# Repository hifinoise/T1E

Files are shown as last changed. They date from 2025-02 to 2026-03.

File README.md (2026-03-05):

# T1E - E-Paper Watch

> Time. For time's sake.

**The T1E is an open-source ePaper smartwatch that lasts for days, not hours. Minimal. Hackable. Yours.**

Because checking your phone for the time is so last decade. The T1E prioritises battery life over flashy animations. Built around an ESP32 microcontroller and a DS3231 RTC, it's designed for people who want their timepiece to actually keep time without requiring daily charging rituals.

---

## Features

- **ePaper Display:** Crystal clear in direct sunlight and uses minimal power.
- **4+ Days Battery Life:** Target 16+ days using intelligent partial refreshes. Charge less, live more.
- **Real-Time Clock:** DS3231 maintains accurate timekeeping even when the main MCU sleeps.
- **Deep Sleep Mode:** Intelligent power management. [Not Implemented on IDF Yet!]
- **Fully Hackable:** 100% open-source hardware, firmware, and mechanical designs.
- **Custom App Modes:** Various watch faces, a Pomodoro timer, a dice roller, and Conway's Game of Life built in.

## What's This Then?

This repository contains the full hardware designs, 3D-printable case models, and the **official, native ESP-IDF firmware** (built via PlatformIO) for the T1E E-Paper Watch. 

Every design choice has a clear reason: the ESP32 wakes up just long enough to refresh the screen, while the external RTC handles timekeeping at micro-amp power levels.

## Repository Contents

```
├── hardware/
│   ├── schematics/        # EasyEDA schematic files (and exported PDFs)
│   ├── pcb/               # PCB layout and gerbers
│   └── bom.csv            # Bill of materials
├── mechanical/
│   ├── case/              # 3D printable case files (STL/STEP)
│   └── assembly/          # Assembly instructions
├── firmware/              
│   ├── V2a/                # ESP-IDF Version (Experimental)
│   └── V1.1/               # Old Arduino-based code
└── docs/                  # Build guides and documentation
```

## Technical Specifications

- **MCU:** ESP32-C3 / ESP32-C6 (RISC-V, Dual-core, WiFi/BLE)
- **Display:** High-contrast ePaper display
- **RTC:** DS3231 with integrated crystal 
- **Power:** LiPo battery with BMS
- **Connectivity:** WiFi 2.4GHz & Bluetooth LE

## Getting Started

### Prerequisites

- PlatformIO
- 3D printer (for the case)
- Basic soldering skills
- Patience (surprisingly important for embedded development)

### Hardware Assembly

1. **PCB Assembly:** Solder components according to the BOM and assembly guide.
2. **Case Printing:** Print case parts using provided STL files.
3. **Final Assembly:** Mount PCB in case, connect battery, install display.

*(Detailed assembly instructions are in `/docs/assembly.md`)*

### Firmware Setup

1. Install [PlatformIO](https://platformio.org/).
2. Clone this repository.
3. Open the repository in PlatformIO.
4. Select your build environment (`env:t1e-c3` or `env:t1e-c6`).
5. Build and flash the firmware to the ESP32 via USB.
6. Set the initial time via the serial console or by configuring the WiFi sync credentials.

## Design Philosophy & Contributing

- **Battery Life First:** ePaper and an RTC combo for minimal power consumption.
- **Hackable by Design:** Built to be modified—not just used. Feel free to tweak the display update logic, design a new case, or implement a fresh display driver.
- **Contributing:** Pull requests are always welcome! Help is particularly appreciated with extreme power optimisation, new UI app modes, and alternative display drivers.

---

## License

- **Hardware:** CERN-OHL-W v2
- **Firmware:** MIT License
- **Mechanical:** CC BY-SA 4.0

## Support & About
For questions, bug reports, or general discussion, open an issue on GitHub.

> *"There is never time in the future in which we will work out our salvation. The challenge is in the moment; the time is always now."* — James Baldwin

*The T1E is a project by [Ampere Works](https://ampere.works/t1e) - part of a mission to make hardware design approachable without dumbing it down.*

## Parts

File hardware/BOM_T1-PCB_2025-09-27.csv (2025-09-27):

ID | Name | Designator | Footprint | Quantity | Manufacturer Part | Manufacturer | Supplier | Supplier Part | Price
1 | Waveshare 1.54inch e-Paper | U1 | WAVESHARE 1.54INCH EPAPER | 1
2 | XIAO ESP32C3 | U8 | XIAO-ESP32C3-MODULE14P-2.54-21X17.8MM | 1
3 | 220kΩ | R3,R4 | RES-TH_BD1.8-L3.2-P7.20-D0.4 | 2 | MF1/8W-220KΩ±1%T52 | 华星机电 | LCSC | C713940 | 0.006
4 | LiPo 502030 3.7V | U6 | BATTERY LIPO 502030 3.7V | 1
5 | Switch | S1,S2 | 6X6X6.0MM 2L THT TACTILE SWITCH | 2
6 | CR927b_Pin | U2 | CR927_PINS | 1
7 | 100kΩ | R1,R2 | RES-TH_BD1.8-L3.2-P7.20-D0.4 | 2 | MF1/8W-100KΩ±1%T52 | 华星机电 | LCSC | C713934 | 0.007
8 | BUZZER-4.0X4.0-2P-SMD | U3 | BUZZER-4.0X4.0-2P-SMD | 1 | GSC4417YA-16R4000 | INGHAi | LCSC | C255308 | 0.994
9 | DS3231 PI | U7 | DS3231 PI | 1
10 | Wareshare eInk SPI Interface | U5 | WAVESHARE_1.54_EINK_DISPLAY_FOOTPRINT | 1

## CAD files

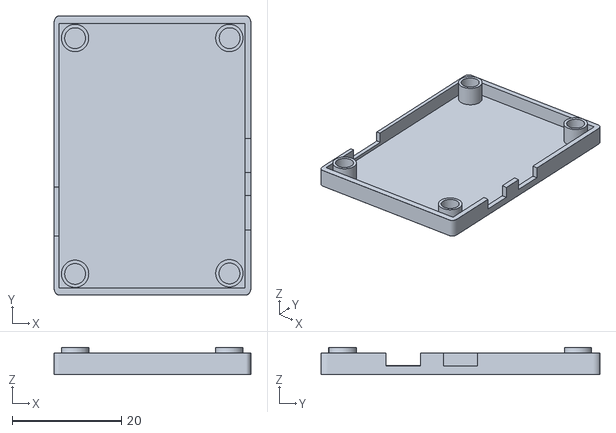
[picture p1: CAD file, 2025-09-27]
mechanical/Case-Bottom-M2.stl
36.0 x 51.0 x 5.00

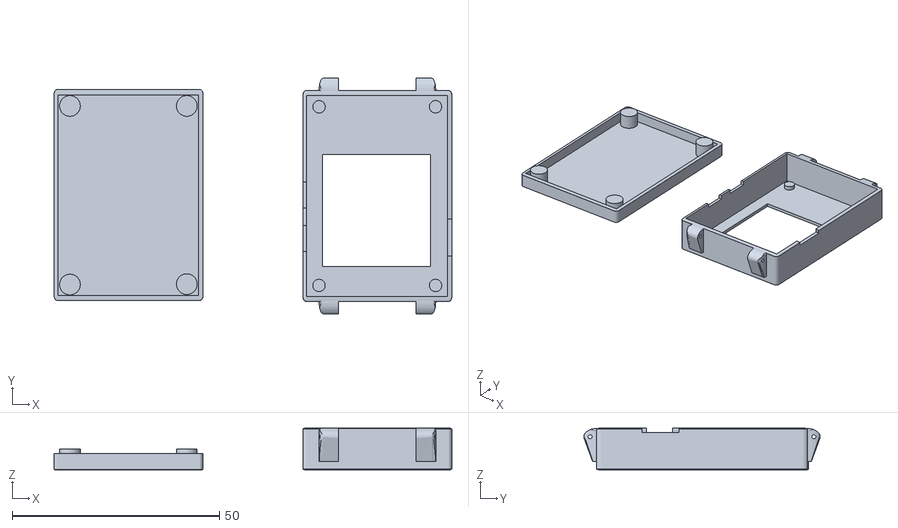
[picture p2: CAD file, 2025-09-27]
mechanical/Case-M2.stl
96.1 x 57.0 x 10.1

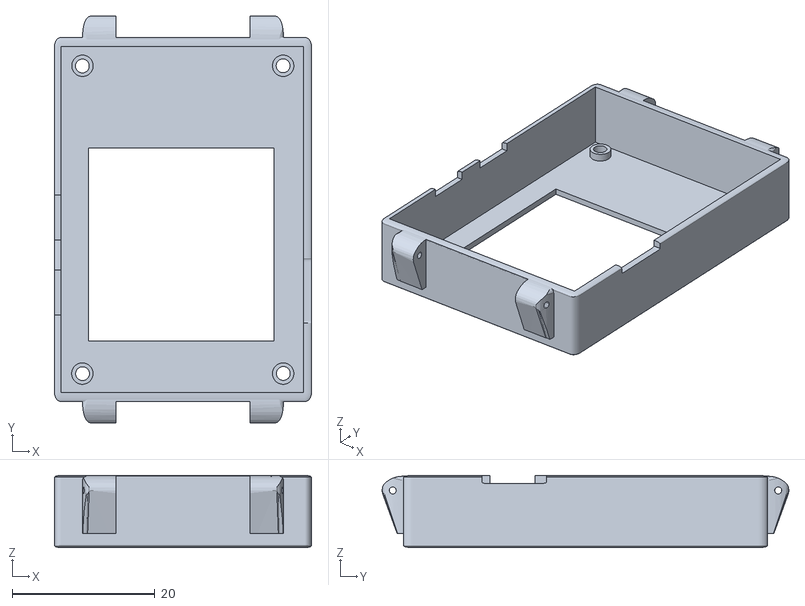
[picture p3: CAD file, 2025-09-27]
mechanical/Case-Top-M2.stl
36.0 x 57.0 x 10.1

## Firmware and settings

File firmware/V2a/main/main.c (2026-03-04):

#include <stdio.h>
#include <string.h>
#include "esp_log.h"
#include "esp_sleep.h"
#include "esp_attr.h"
#include "freertos/FreeRTOS.h"
#include "freertos/task.h"

#include "hal/hal.h"
#include "hal/hal_pins.h"
#include "drivers/epd/epd.h"
#include "drivers/epd/epd_gfx.h"
#include "drivers/rtc/rtc_ds3231.h"
#include "app/state.h"
#include "app/modes/mode_clock.h"
#include "app/modes/mode_life_clock.h"
#include "app/modes/mode_dice.h"
#include "app/modes/mode_art.h"
#include "app/modes/mode_pomo.h"
#include "app/modes/mode_life.h"
#include "app/modes/mode_settings.h"

static const char *TAG = "t1e";

// Framebuffers in regular SRAM — NOT RTC slow memory
static uint8_t fb[EPD_FB_SIZE];
static uint8_t prev_fb[EPD_FB_SIZE];

// refresh_speed index → update interval in milliseconds
static const uint32_t REFRESH_MS[REFRESH_SPEED_COUNT] = {100, 250, 500, 1000, 10000, 60000};

// deghost_idx → ms between full-white deghost refresh (0 = disabled)
static const uint32_t DEGHOST_MS[DEGHOST_IDX_COUNT] = {5*60*1000, 15*60*1000, 30*60*1000, 0};

static void render(t1e_state_t *s) {
    switch (s->mode) {
        case MODE_CLOCK:      mode_clock_render(fb, s);      break;
        case MODE_LIFE_CLOCK: mode_life_clock_render(fb, s); break;
        case MODE_DICE:       mode_dice_render(fb, s);       break;
        case MODE_ART:        mode_art_render(fb, s);        break;
        case MODE_POMO:       mode_pomo_render(fb, s);       break;
        case MODE_LIFE:       mode_life_render(fb, s);       break;
        case MODE_SETTINGS:   mode_settings_render(fb, s);   break;
        default:              mode_clock_render(fb, s);       break;
    }
}

static void action(t1e_state_t *s) {
    switch (s->mode) {
        case MODE_CLOCK:      mode_clock_action(s);      break;
        case MODE_LIFE_CLOCK: mode_life_clock_action(s); break;
        case MODE_DICE:       mode_dice_action(s);       break;
        case MODE_ART:        mode_art_action(s);        break;
        case MODE_POMO:       mode_pomo_action(s);       break;
        case MODE_LIFE:       mode_life_action(s);       break;
        case MODE_SETTINGS:   mode_settings_action(s);   break;
        default: break;
    }
}

void app_main(void) {
    ESP_LOGI(TAG, "=== T1E BOOT ===");

    hal_buttons_init();
    hal_power_init();
    if (!rtc_init()) ESP_LOGE(TAG, "RTC FAILED");
    epd_init();

    t1e_state_t *s = state_get();
    if (s->magic != STATE_MAGIC) {
        state_init_defaults(s);
    }

    // Cold boot: full refresh to establish clean baseline in both RAMs
    render(s);
    if (s->display_invert)
        for (int i = 0; i < EPD_FB_SIZE; i++) fb[i] ^= 0xFF;
    epd_refresh_full(fb);
    memcpy(prev_fb, fb, EPD_FB_SIZE);

    uint32_t last_refresh = xTaskGetTickCount();
    uint32_t ghost_timer  = xTaskGetTickCount();

    while (1) {
        btn_state_t btn = hal_buttons_read();
        bool need_refresh = false;
        bool force_full   = false;
        bool do_deghost   = false;

        // --- Button A: secondary action ---
        if (btn.a) {
            action(s);
            need_refresh = true;
        }

        // --- Button B: confirm / mode advance ---
        if (btn.b) {
            if (s->mode == MODE_SETTINGS) {
                uint8_t invert_before = s->display_invert;
                mode_settings_confirm(s);
                // If invert just toggled, force a full refresh to reset RAM baseline
                if (s->display_invert != invert_before) force_full = true;
            } else if (s->mode == MODE_DICE) {
                if (s->dice_type < DICE_COUNT - 1) {
                    s->dice_type++;
                    s->last_roll = 0;
                } else {
                    s->dice_type = DICE_D20;
                    s->last_roll = 0;
                    state_next_mode(s);
                }
            } else {
                state_next_mode(s);
            }
            need_refresh = true;
        }

        // --- Time-based refresh ---
        uint32_t now = xTaskGetTickCount(); // ticks (1 tick = 1ms at default ESP32 config)
        uint32_t interval_ticks = pdMS_TO_TICKS(REFRESH_MS[s->refresh_speed % REFRESH_SPEED_COUNT]);
        // POMO countdown always needs 1s resolution
        if (s->mode == MODE_POMO && s->pomo_start) interval_ticks = pdMS_TO_TICKS(1000);

        static int last_min = -1;
        if (s->mode == MODE_CLOCK || s->mode == MODE_LIFE_CLOCK) {
            // For clock modes, only refresh when the minute actually changes.
            // We ignore interval_ticks entirely, but poll gently every 1 second.
            if (now - last_refresh >= pdMS_TO_TICKS(1000)) {
                rtc_time_t t = {0};
                if (rtc_get_time(&t)) {
                    if (t.min != last_min) {
                        need_refresh = true;
                        last_min = t.min;
                    }
                }
                last_refresh = now;
            }
        } else {
            // Normal global refresh interval for non-clock modes
            if (now - last_refresh >= interval_ticks) {
                need_refresh = true;
                last_refresh = now;
            }
        }

        // --- Deghost watchdog ---
        // Banks display to all-white then partial-refreshes back to current frame.
        // This clears image retention without a jarring double-flash.
        uint32_t dghost_ms = DEGHOST_MS[s->deghost_idx % DEGHOST_IDX_COUNT];
        if (dghost_ms > 0 && now - ghost_timer >= pdMS_TO_TICKS(dghost_ms)) {
            do_deghost   = true;
            need_refresh = true;
            ghost_timer  = now;
        }

        // --- Render and refresh ---
        if (need_refresh) {
            render(s);

            // Apply inversion if enabled
            if (s->display_invert)
                for (int i = 0; i < EPD_FB_SIZE; i++) fb[i] ^= 0xFF;

            if (do_deghost) {
                // Full white refresh to clear ghosting, then partial back to frame
                epd_deghost(fb);
                s->partial_count = 0;
            } else if (force_full) {
                epd_refresh_full(fb);
                s->partial_count = 0;
            } else {
                epd_refresh_animate(prev_fb, fb, &s->partial_count);
            }

            memcpy(prev_fb, fb, EPD_FB_SIZE);
        }

        vTaskDelay(pdMS_TO_TICKS(30));
    }
}

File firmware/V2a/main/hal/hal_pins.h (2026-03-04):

#pragma once

// T1E Pin Definitions
// The PCB routes XIAO module pads to peripherals differently per variant.
// Arduino code used raw GPIO numbers — we do the same here in ESP-IDF.

#include "hal/spi_types.h"
#include "driver/i2c_types.h"

#ifdef BOARD_VARIANT_C3
// ---- XIAO ESP32-C3 (from T1E_Battery_C3.ino) ----
// Default SPI: MOSI=GPIO10(D10), SCK=GPIO8(D8)
#define PIN_SPI_MOSI    10
#define PIN_SPI_CLK     8
#define PIN_EPD_CS      5       // D3
#define PIN_EPD_DC      20      // D7
#define PIN_EPD_RST     21      // D6
#define PIN_EPD_BUSY    9       // D9
#define EPD_SPI_HOST    SPI2_HOST

// I2C: SDA=GPIO6(D4), SCL=GPIO7(D5)
#define PIN_I2C_SDA     6
#define PIN_I2C_SCL     7
#define I2C_PORT        I2C_NUM_0

// Buttons
#define PIN_BTN_A       3       // D1
#define PIN_BTN_B       4       // D2

// Battery ADC
#define PIN_BATT_ADC    2       // D0/A0
#define BATT_ADC_CHAN   ADC_CHANNEL_2

#else
// ---- XIAO ESP32-C6 (from T1E.ino) ----
// Default SPI: MOSI=GPIO18(D10), SCK=GPIO19(D8), MISO=GPIO20(D9)
#define PIN_SPI_MOSI    18
#define PIN_SPI_CLK     19
#define PIN_EPD_CS      21      // D3
#define PIN_EPD_DC      17      // D7
#define PIN_EPD_RST     16      // D6
#define PIN_EPD_BUSY    20      // D9 — shared with MISO pad but used as GPIO
#define EPD_SPI_HOST    SPI2_HOST

// I2C: SDA=GPIO22(D4), SCL=GPIO23(D5)
#define PIN_I2C_SDA     22
#define PIN_I2C_SCL     23
#define I2C_PORT        I2C_NUM_0

// Buttons
#define PIN_BTN_A       1       // D1
#define PIN_BTN_B       2       // D2

// Battery ADC
#define PIN_BATT_ADC    0       // D0/A0
#define BATT_ADC_CHAN   ADC_CHANNEL_0

#endif

// Common
#define I2C_FREQ_HZ     100000
#define DS3231_ADDR     0x68
#define EPD_WIDTH       200
#define EPD_HEIGHT      200
#define EPD_FB_SIZE     (EPD_WIDTH * EPD_HEIGHT / 8)

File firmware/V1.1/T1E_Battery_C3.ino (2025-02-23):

#include <GxEPD2_BW.h>
#include <Wire.h>
#include <RTClib.h>
#include <WiFi.h>
#include <NTPClient.h>
#include <WiFiUdp.h>
#include <Fonts/FreeMonoBold24pt7b.h> // Large font for time
#include <Fonts/FreeMonoBold12pt7b.h> // Smaller font for date
#include <Adafruit_GFX.h>
#include "example_wifi_credentials.h" // Include Wi-Fi credentials
#include <esp_sleep.h>

#define uS_TO_S_FACTOR 1000000ULL /* Conversion factor for microseconds to seconds */
#define TIME_TO_SLEEP  60        /* Time ESP32 will go to sleep (in seconds) */

// GPIO bitmasks for wakeup
#define BUTTON_1 (1ULL << GPIO_NUM_3) // GPIO 1 bitmask for EXT1 wakeup
#define BUTTON_2 (1ULL << GPIO_NUM_4) // GPIO 2 bitmask for EXT1 wakeup

// E-paper display pin configuration
#define EPD_CS    5
#define EPD_DC    20
#define EPD_RST   21
#define EPD_BUSY  9

// Button pins
#define BUTTON_WIFI GPIO_NUM_3   // Button to connect Wi-Fi
#define BUTTON_SET  GPIO_NUM_4   // Button to set custom time

// Battery monitoring pin
#define BATTERY_PIN 2

// Delay sleep if required
int delaySleep = 0;

// NTP server settings
const long utcOffsetInSeconds = 19800; // UTC+5:30 for IST

// Battery monitoring variables
float batteryVoltage = 0.0;
const float voltageDividerRatio = 2.0; // 1/2 attenuation ratio
int battPercent = 0;

// Initialize display
GxEPD2_BW<GxEPD2_154_GDEY0154D67, GxEPD2_154_GDEY0154D67::HEIGHT> display(GxEPD2_154_GDEY0154D67(EPD_CS, EPD_DC, EPD_RST, EPD_BUSY));

// Initialize RTC
RTC_DS3231 rtc;

// Initialize NTP client
WiFiUDP ntpUDP;
NTPClient timeClient(ntpUDP, "pool.ntp.org", utcOffsetInSeconds);

void setup() {
  // Begin Serial for debugging
  Serial.begin(115200);

  // Initialize I2C (use Xiao ESP32-C3 default pins)
  Wire.begin(6, 7);

  // Initialize e-paper display
  display.init();

  // Initialize RTC
  if (!rtc.begin()) {
    Serial.println("Couldn't find RTC");
    while (1);
  }

  if (rtc.lostPower()) {
    Serial.println("RTC lost power, setting time to compile time!");
    rtc.adjust(DateTime(F(__DATE__), F(__TIME__)));
  }

  // Configure button pins
  pinMode(BUTTON_WIFI, INPUT);
  pinMode(BUTTON_SET, INPUT);

  // Handle button logic
  buttonLogic();

  // Update battery voltage
  updateBatteryVoltage();

  // Update the display
  updateDisplay();

  // Go to sleep if not in Set Time mode
  sleepCycle();
}

void loop() {
  // Should never get here, as the ESP will wake up from deep sleep
}

void connectToWiFi() {
  Serial.println("Connecting to Wi-Fi...");
  WiFi.begin(ssid, password);

  unsigned long startAttemptTime = millis();
  const unsigned long timeout = 10000; // 10 seconds timeout

  while (WiFi.status() != WL_CONNECTED && millis() - startAttemptTime < timeout) {
    delay(500);
    Serial.print(".");
  }

  if (WiFi.status() == WL_CONNECTED) {
    Serial.println("\nConnected to Wi-Fi");
    Serial.print("IP Address: ");
    Serial.println(WiFi.localIP());
  } else {
    Serial.println("\nFailed to connect to Wi-Fi");
  }
}

void checkAndSyncTime() {
  if (WiFi.status() != WL_CONNECTED) {
    updateDisplay();
  }

  timeClient.update();
  DateTime now = rtc.now();
  unsigned long currentEpoch = timeClient.getEpochTime();

  if (abs((long)(now.unixtime() - currentEpoch)) > 10) {
    Serial.println("Time discrepancy detected, updating RTC...");
    rtc.adjust(DateTime(currentEpoch));
  }

  WiFi.disconnect(true);
  WiFi.mode(WIFI_OFF);
}

void updateBatteryVoltage() {
  uint32_t Vbatt = 0;
  for (int i = 0; i < 16; i++) {
    Vbatt += analogReadMilliVolts(BATTERY_PIN); // ADC with correction
  }
  int batt = voltageDividerRatio * Vbatt / 16;
  batteryVoltage = voltageDividerRatio * Vbatt / 16 / 1000.0; // mV to V
  battPercent = map(batt, 3200, 4180, 0, 100);
}

void updateDisplay() {
  DateTime now = rtc.now();
  char timeBuffer[10];
  snprintf(timeBuffer, sizeof(timeBuffer), "%02d:%02d", now.hour(), now.minute());

  char dateBuffer[20];
  snprintf(dateBuffer, sizeof(dateBuffer), "%02d %s", now.day(), monthName(now.month()));

  display.firstPage();
  do {
    display.fillScreen(GxEPD_BLACK);
    display.setTextColor(GxEPD_WHITE);

    // Display time, centered
    display.setFont(&FreeMonoBold24pt7b);
    int16_t x1, y1;
    uint16_t w, h;
    display.getTextBounds(timeBuffer, 0, 0, &x1, &y1, &w, &h);
    display.setCursor((display.width() - w) / 2, 100);
    display.print(timeBuffer);

    // Display date, centered
    display.setFont(&FreeMonoBold12pt7b);
    display.getTextBounds(dateBuffer, 0, 0, &x1, &y1, &w, &h);
    display.setCursor((display.width() - w) / 2, 150);
    display.print(dateBuffer);

    // Draw battery icon
    drawBatteryIcon();
    
  } while (display.nextPage());
}

const char* monthName(int month) {
  const char* monthNames[] = {"Jan", "Feb", "Mar", "Apr", "May", "Jun",
                              "Jul", "Aug", "Sep", "Oct", "Nov", "Dec"};
  return monthNames[month - 1];
}

void drawBatteryIcon() {
  int x = 158, y = 3;
  display.drawRect(x, y, 30, 15, GxEPD_WHITE); // Battery Outline 
  display.fillRect(x + 31, y + 4, 2, 6, GxEPD_WHITE); // Battery terminal
  int fillWidth = (int)(30 * battPercent / 100); // Scale for 4.2V max
  display.fillRect(x + 1, y + 1, fillWidth, 13, GxEPD_WHITE);
   
  // Uncomment for Battery Status
 display.setCursor(120, 40);
 display.print(String(batteryVoltage) + "V");
 display.setCursor(142, 60);
 display.print(String(battPercent) + "%");

  // Low battery indication
  if (batteryVoltage < 3.2) {
    display.setCursor(140, 80);
    display.print("LOW"); }
}

void sleepCycle() {
  // Protect against deep discharge
  if (batteryVoltage < 3.2) {
    Serial.println("Battery critically low. Shutting down indefinitely to prevent damage.");
    esp_sleep_disable_wakeup_source(ESP_SLEEP_WAKEUP_TIMER); // Disable Timer wakeup
    esp_deep_sleep_start(); // Enter indefinite deep sleep
  }
 


  // Configure GPIO wakeup
  esp_sleep_enable_gpio_wakeup();

  // Configure wakeup pins (low level triggers wakeup)
  esp_deep_sleep_enable_gpio_wakeup(BUTTON_1, ESP_GPIO_WAKEUP_GPIO_LOW);
  esp_deep_sleep_enable_gpio_wakeup(BUTTON_2, ESP_GPIO_WAKEUP_GPIO_LOW);

  // Enable timer wakeup
  esp_sleep_enable_timer_wakeup(TIME_TO_SLEEP * uS_TO_S_FACTOR); // Wakeup timer
   
   
   //Delay Sleep
  delay (delaySleep);
  delaySleep = 0;

  
  // Enter deep sleep
  esp_deep_sleep_start();


}

void buttonLogic() {
  // If Wi-Fi button is pressed, connect to Wi-Fi and update time
  if (digitalRead(BUTTON_WIFI) == LOW) {
    connectToWiFi();
    checkAndSyncTime();
    delaySleep = 0;

  }

  // If the set time button is pressed, enter the Set Time mode
  if (digitalRead(BUTTON_SET) == LOW) {
    updateFirmware();
  }
}

void updateFirmware() {
delaySleep = 180000;

}

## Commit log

2024-11-04 Code for initial PCB Version
    - Using the GxEPD2 library and 1.54-inch Waveshare E-paper display module to show time in a crispy manner.
    - Added the DS3231 RTC to keep the ESP32 on schedule, even after a nap, a power tantrum, a moderate EMP, not water weather-related acts of god, cosmic ray strikes etc.
    - Set up NTP sync, because the internet.
    - Battery monitoring, this is like a real consumer electronics thing now.
    - Deep sleep mode added for those power-saving siestas, with wake-ups on GPIO 1 & 2.
    - Buttons now do more than look pretty: Wi-Fi sync and; well the other one just looks pretty for now.
2025-09-27 Added Readme and reformatted the git.
    Added
    STLs
    PCB Files
    BOM
    [BOM_T1-PCB_2025-09-27.csv, Case-Bottom-M2.stl, Case-M2.stl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]
2026-03-04 Added new Firmware
    Moved firmware to Platfom.IO and ESP-IDF. Added Fast Partial Refresh (250ms) and Game of Life, Timer and Dice Modes.
    Also Added Settings Menu.
    Removed Deep Sleep for testing.
    [partitions.csv]
2026-03-05 Added new Firmware
    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
    [partitions.csv]
